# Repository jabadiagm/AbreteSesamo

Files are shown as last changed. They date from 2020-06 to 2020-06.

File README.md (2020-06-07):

# Ábrete Sésamo
Detector de proximidad / apertura de puertas por bluetooth

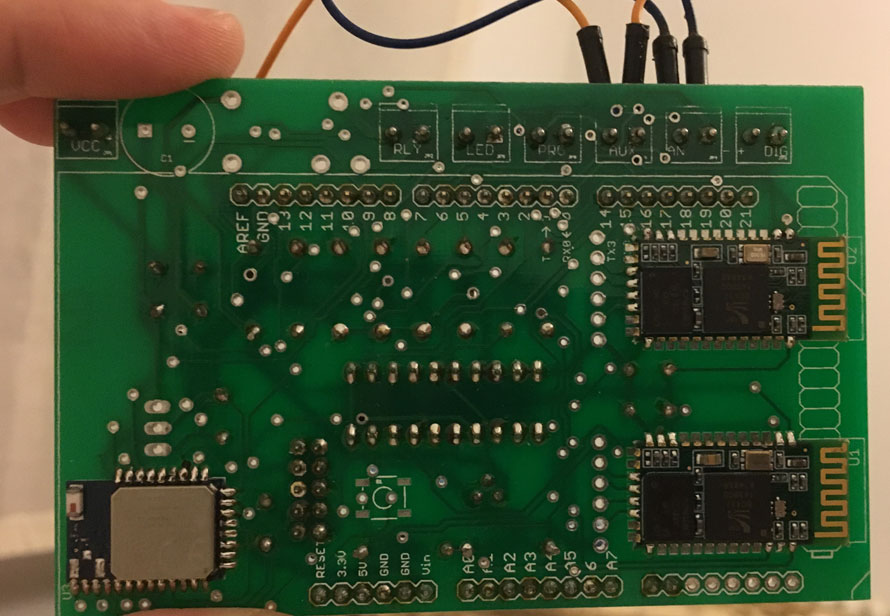
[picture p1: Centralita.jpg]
Centralita


Ábrete Sésamo es un detector de proximidad basado en bluetooth que permite abrir la puerta de un hogar o de un garaje al detectar un dispositivo bluetooth dentro de un rango de 10m, aproximadamente. La centralita está formada por un arduino mega y una placa auxiliar. La placa contiene un relé para conectar al circuito de apertura y tres chips de bluetooth (2xHC05 + BLE112). El primer HC05 sirve para detectar teléfonos anteriores a los smartphones. El segundo HC05 detecta smartphones con bluetooth 1-3. Y el BLE112 sirve para smartphones con bluetooth 4. Los smartphones deben incluir una aplicación que se comunique con la centralita.

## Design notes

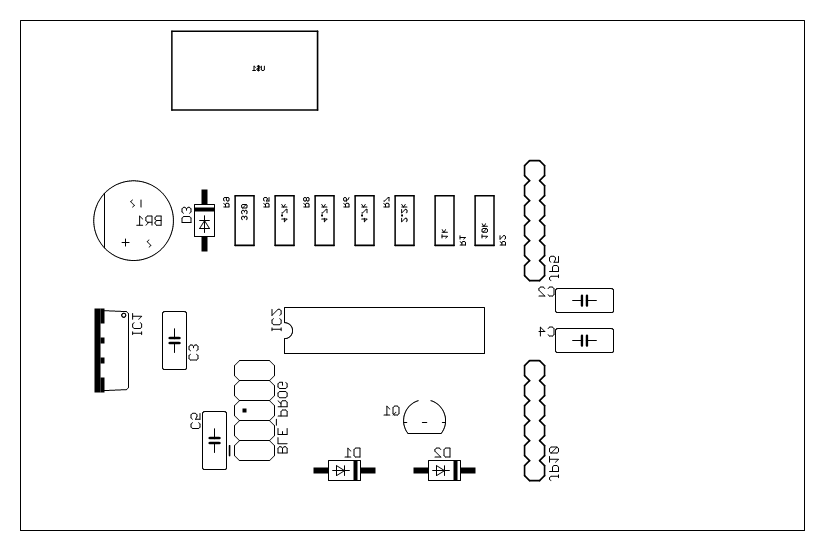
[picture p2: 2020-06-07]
eagle/Images for gerber/prototipo_2_0.GBO.png

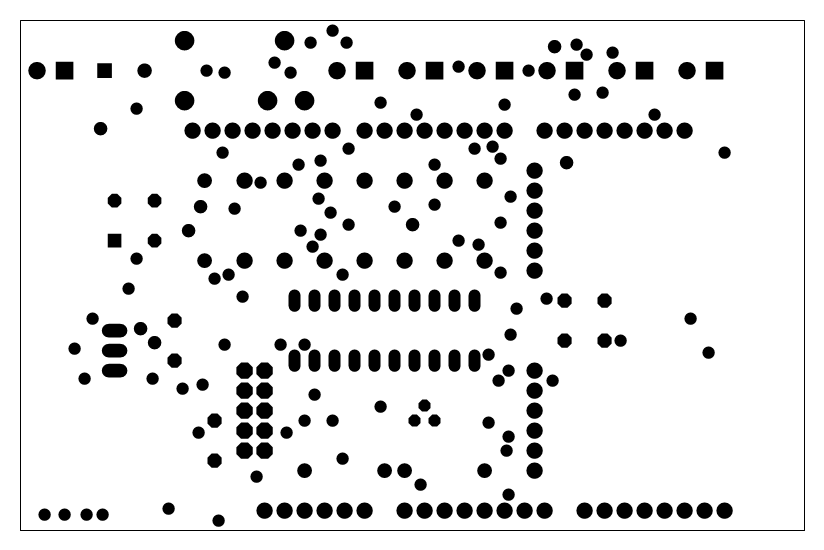
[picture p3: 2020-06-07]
eagle/Images for gerber/prototipo_2_0.GBS.png

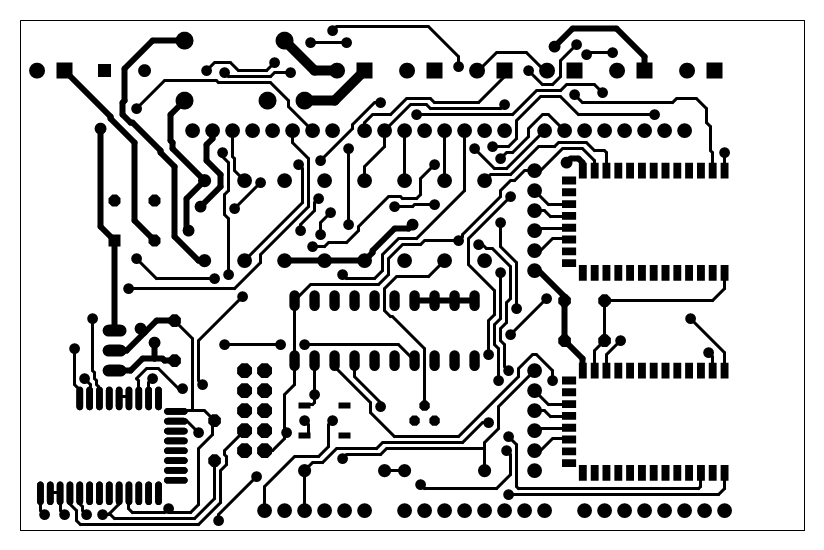
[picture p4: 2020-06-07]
eagle/Images for gerber/prototipo_2_0.GTL.png

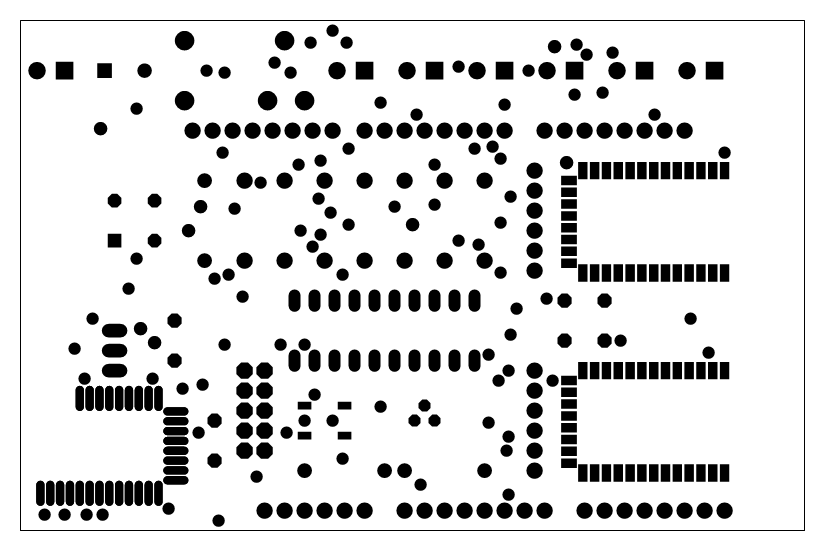
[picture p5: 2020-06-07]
eagle/Images for gerber/prototipo_2_0.GTS.png

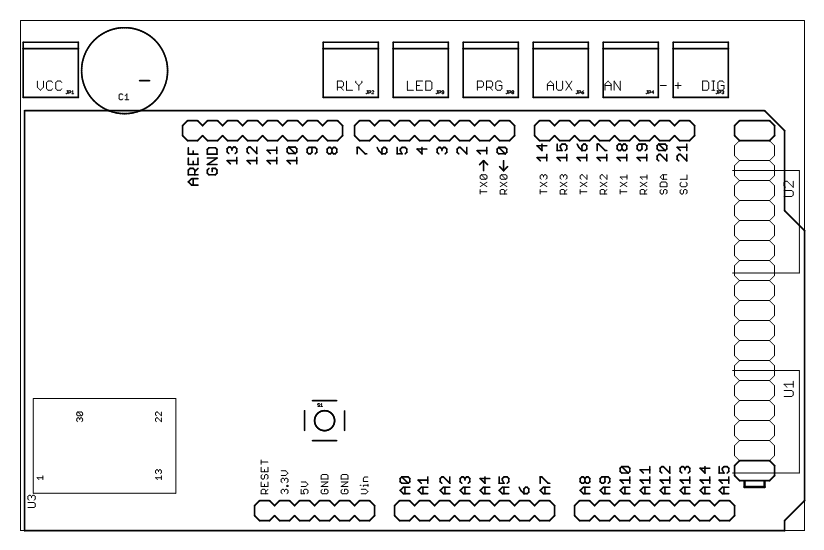
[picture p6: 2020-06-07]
eagle/Images for gerber/prototipo_2_0.GTO.png

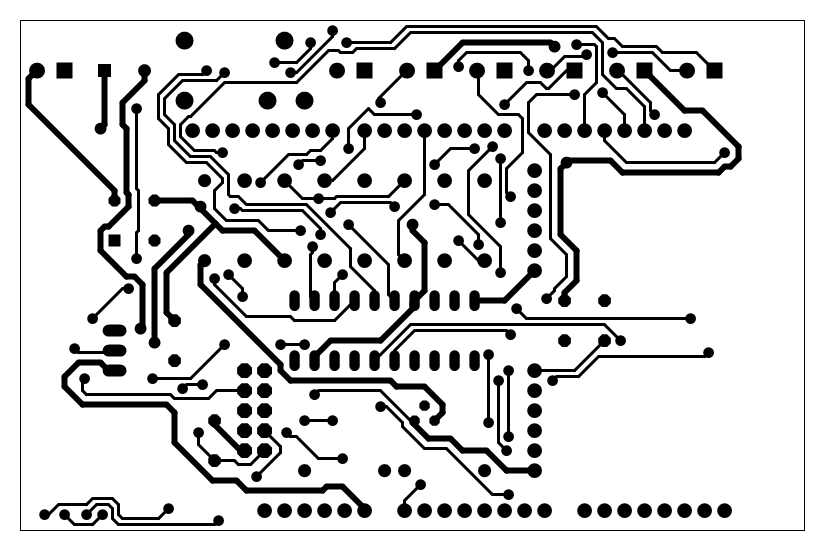
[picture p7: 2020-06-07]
eagle/Images for gerber/prototipo_2_0.GBL.png

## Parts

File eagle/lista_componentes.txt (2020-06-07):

Partlist

Exported from prototipo_2_0.sch at 14/11/2012 22:06:32

EAGLE Version 6.1.0 Copyright (c) 1988-2012 CadSoft

Assembly variant: 

Part     Value           Device                Package                Library                    Sheet

BLE_PROG M05X2PTH        M05X2PTH              AVR_ICSP               SparkFun-Connectors        1
BR1      W05G            W05G                  WOG                    dbridge                    1
C1       500uF           CAP_POLPTH4           CPOL-RADIAL-1000UF-25V SparkFun-Passives          1
C2       100n            C5/3                  C5B3                   capacitor-wima             1
C3       100n            C5/3                  C5B3                   capacitor-wima             1
C4       100n            C5/3                  C5B3                   capacitor-wima             1
C5       100n            C5/3                  C5B3                   capacitor-wima             1
D1       1N4004          1N4004                DO41-10                diode                      1
D2       1N4004          1N4004                DO41-10                diode                      1
D3       1N4004          1N4004                DO41-10                diode                      1
IC1      788TV           788TV                 TO220V                 linear                     1
IC2      74LS245N        74LS245N              DIL20                  adafruit                   1
JP1      VCC             M023.5MM              SCREWTERMINAL-3.5MM-2  SparkFun-Connectors        1
JP2      RLY             M023.5MM              SCREWTERMINAL-3.5MM-2  SparkFun-Connectors        1
JP3      PR1             M023.5MM              SCREWTERMINAL-3.5MM-2  SparkFun-Connectors        1
JP4      PR2             M023.5MM              SCREWTERMINAL-3.5MM-2  SparkFun-Connectors        1
JP5      SPI             M06SIP                1X06                   SparkFun-Connectors        1
JP6      AUX             M023.5MM              SCREWTERMINAL-3.5MM-2  SparkFun-Connectors        1
JP8      PRG             M023.5MM              SCREWTERMINAL-3.5MM-2  SparkFun-Connectors        1
JP9      LED             M023.5MM              SCREWTERMINAL-3.5MM-2  SparkFun-Connectors        1
JP10     SPI             M06SIP                1X06                   SparkFun-Connectors        1
Q1       BC547           BC547                 TO92                   transistor-npn             1
R1       1k              RESISTORPTH-1/4W      AXIAL-0.4              SparkFun-Passives          1
R2       10k             RESISTORPTH-1/4W      AXIAL-0.4              SparkFun-Passives          1
R5       4.7k            RESISTORPTH-1/4W      AXIAL-0.4              SparkFun-Passives          1
R6       4.7k            RESISTORPTH-1/4W      AXIAL-0.4              SparkFun-Passives          1
R7       2.2k            RESISTORPTH-1/4W      AXIAL-0.4              SparkFun-Passives          1
R8       4.7k            RESISTORPTH-1/4W      AXIAL-0.4              SparkFun-Passives          1
R9       330             RESISTORPTH-1/4W      AXIAL-0.4              SparkFun-Passives          1
S1       RESET           SWITCH-MOMENTARY-2SMD TACTILE_SWITCH_SMD     SparkFun-Electromechanical 1
U$1      RELAYPTH4       RELAYPTH4             RELAY-JZC              SparkFun-Electromechanical 1
U$2      ARDUINOMEGA_100 ARDUINOMEGA_100       ARDUINOMEGA_100        prymia                     1
U1       HC_05           HC_05                 BLUETOOTH_SMD          SerialPortBluetooth        1
U2       HC_05           HC_05                 BLUETOOTH_SMD          SerialPortBluetooth        1
U3       BLE112          BLE112-A-VISUAL       BLE112-A               sf-bluegiga                1

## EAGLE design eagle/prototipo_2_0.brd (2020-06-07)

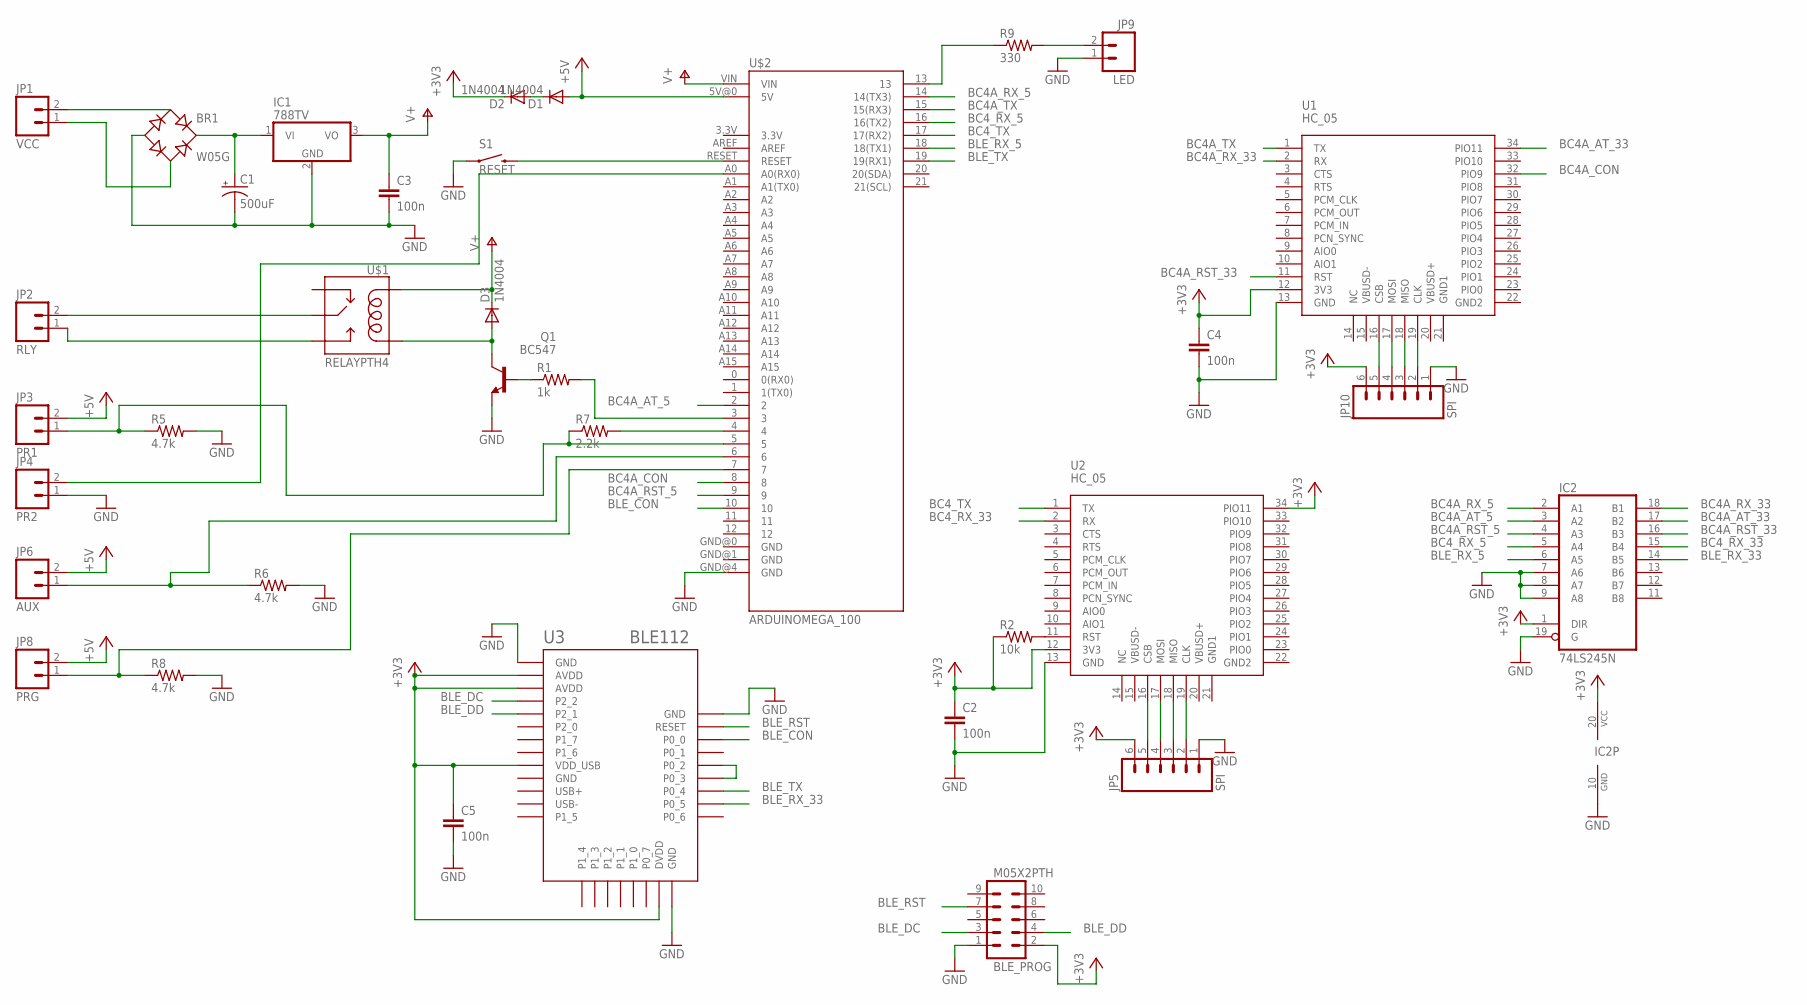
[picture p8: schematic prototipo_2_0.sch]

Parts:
BLE_PROG: M05X2PTH; AVR_ICSP
BR1: W05G; WOG
C1: 500uF; CPOL-RADIAL-1000UF-25V
C2, C3, C4, C5: 100n; C5B3
D1, D2, D3: 1N4004; DO41-10
IC1: 788TV; TO220V
IC2: 74LS245N; DIL20
JP1: VCC; SCREWTERMINAL-3.5MM-2
JP2: RLY; SCREWTERMINAL-3.5MM-2
JP3: PR1; SCREWTERMINAL-3.5MM-2
JP4: PR2; SCREWTERMINAL-3.5MM-2
JP5, JP10: SPI; 1X06
JP6: AUX; SCREWTERMINAL-3.5MM-2
JP8: PRG; SCREWTERMINAL-3.5MM-2
JP9: LED; SCREWTERMINAL-3.5MM-2
Q1: BC547; TO92
R1: 1k; AXIAL-0.4
R2: 10k; AXIAL-0.4
R5, R6, R8: 4.7k; AXIAL-0.4
R7: 2.2k; AXIAL-0.4
R9: 330; AXIAL-0.4
S1: RESET; TACTILE_SWITCH_SMD
U1, U2: HC_05; BLUETOOTH_SMD
U3: BLE112; BLE112-A
U$1: RELAYPTH4; RELAY-JZC
U$2: ARDUINOMEGA_100

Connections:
+3V3: BLE_PROG.2, C2.1, C4.1, C5.1, D2.C, IC2.1 (DIR), IC2.20 (VCC), JP5.6, JP10.6, R2.P$1 (1), U1.12 (3V3), U2.12 (3V3), U2.34 (PIO11), U3.AVDD1 (AVDD), U3.AVDD2 (AVDD), U3.DVDD, U3.VDD_USB
+5V: D1.A, JP3.2, JP6.2, JP8.2, U$2.5V@0 (5V)
BC4A_AT_5: IC2.3 (A2), U$2.2
BC4A_AT_33: IC2.17 (B2), U1.34 (PIO11)
BC4A_CON: U1.32 (PIO9), U$2.8
BC4A_RST_5: IC2.4 (A3), U$2.9
BC4A_RST_33: IC2.16 (B3), U1.11 (RST)
BC4A_RX_5: IC2.2 (A1), U$2.14 (14(TX3))
BC4A_RX_33: IC2.18 (B1), U1.2 (RX)
BC4A_TX: U1.1 (TX), U$2.15 (15(RX3))
BC4_RX_5: IC2.5 (A4), U$2.16 (16(TX2))
BC4_RX_33: IC2.15 (B4), U2.2 (RX)
BC4_TX: U2.1 (TX), U$2.17 (17(RX2))
BLE_CON: U3.P0_0, U$2.10
BLE_DC: BLE_PROG.3, U3.P2_2
BLE_DD: BLE_PROG.4, U3.P2_1
BLE_RST: BLE_PROG.7, U3.RESET
BLE_RX_5: IC2.6 (A5), U$2.18 (18(TX1))
BLE_RX_33: IC2.14 (B5), U3.P0_5
BLE_TX: U3.P0_4, U$2.19 (19(RX1))
GND: BLE_PROG.1, BR1.-, C1.2 (-), C2.2, C3.2, C4.2, C5.2, IC1.2 (GND), IC2.7 (A6), IC2.8 (A7), IC2.9 (A8), IC2.10 (GND), IC2.19 (G), JP4.1, JP5.1, JP9.1, JP10.1, Q1.1 (E), R5.P$2 (2), R6.P$2 (2), R8.P$2 (2), S1.1, U1.13 (GND), U2.13 (GND), U3.GND1 (GND), U3.GND2 (GND), U3.GND3 (GND), U3.GND4 (GND), U$2.GND@4 (GND)
unnamed: R2.P$2 (2), U2.11 (RST)
unnamed: D1.C, D2.A
unnamed: BR1.+, C1.1 (+), IC1.1 (VI)
unnamed: R1.P$2 (2), U$2.3
unnamed: Q1.2 (B), R1.P$1 (1)
unnamed: D3.A, Q1.3 (C), U$1.1 (COIL2)
unnamed: JP2.1, U$1.3 (NO)
unnamed: JP2.2, U$1.4 (MAIN)
unnamed: S1.3 (2), U$2.RESET
unnamed: U3.P0_2, U3.P0_3
unnamed: JP5.2, U2.19 (CLK)
unnamed: JP5.3, U2.18 (MISO)
unnamed: JP5.4, U2.17 (MOSI)
unnamed: JP5.5, U2.16 (CSB)
unnamed: JP10.5, U1.16 (CSB)
unnamed: JP3.1, R5.P$1 (1), R7.P$1 (1), U$2.5
unnamed: JP6.1, R6.P$1 (1), U$2.6
unnamed: R7.P$2 (2), U$2.4
unnamed: JP8.1, R8.P$1 (1), U$2.7
unnamed: JP10.4, U1.17 (MOSI)
unnamed: R9.P$1 (1), U$2.13
unnamed: JP9.2, R9.P$2 (2)
unnamed: JP10.3, U1.18 (MISO)
unnamed: JP10.2, U1.19 (CLK)
unnamed: JP4.2, U$2.A0 (A0(RX0))
V+: C3.1, D3.C, IC1.3 (VO), U$1.5 (COIL1), U$2.VIN
VCC1: BR1.AC1, JP1.2
VCC2: BR1.AC2, JP1.1

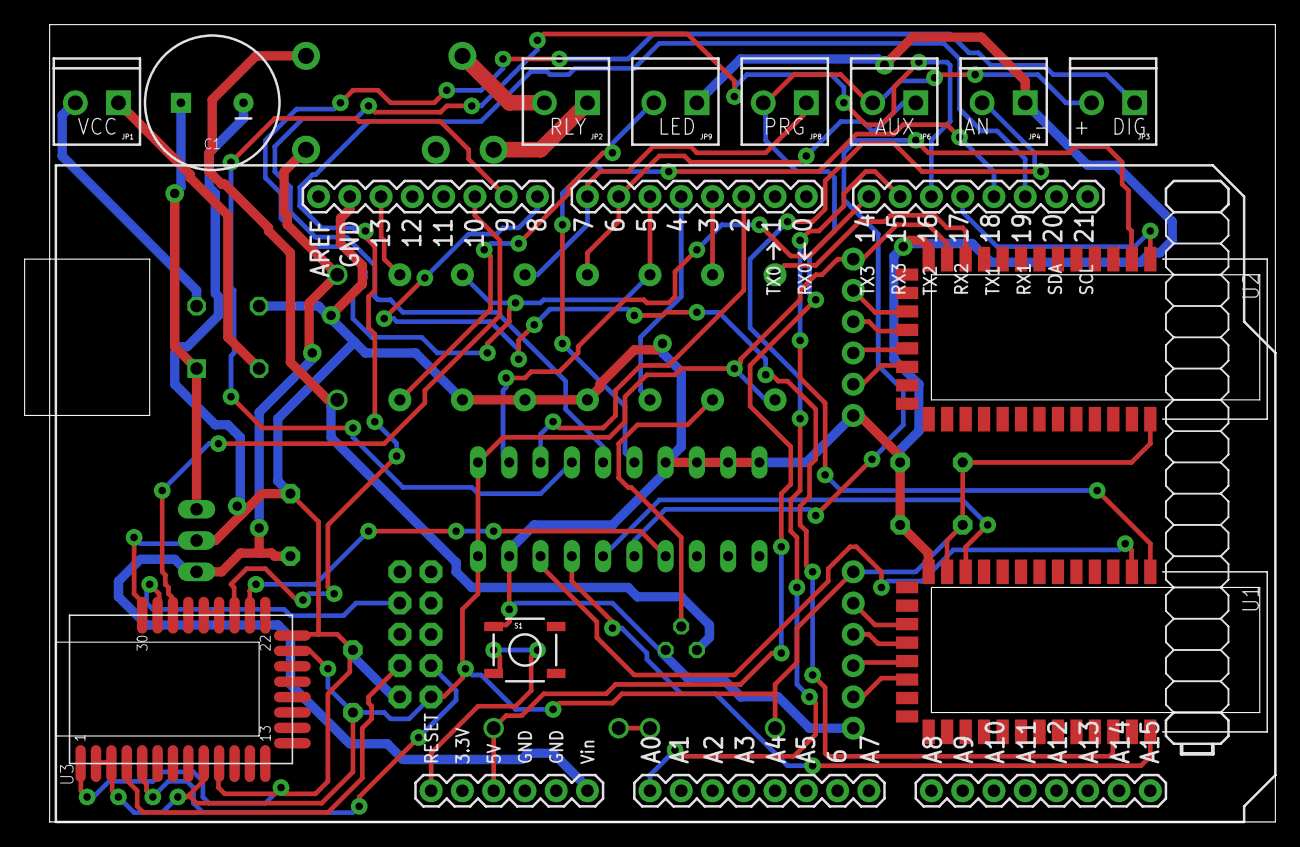
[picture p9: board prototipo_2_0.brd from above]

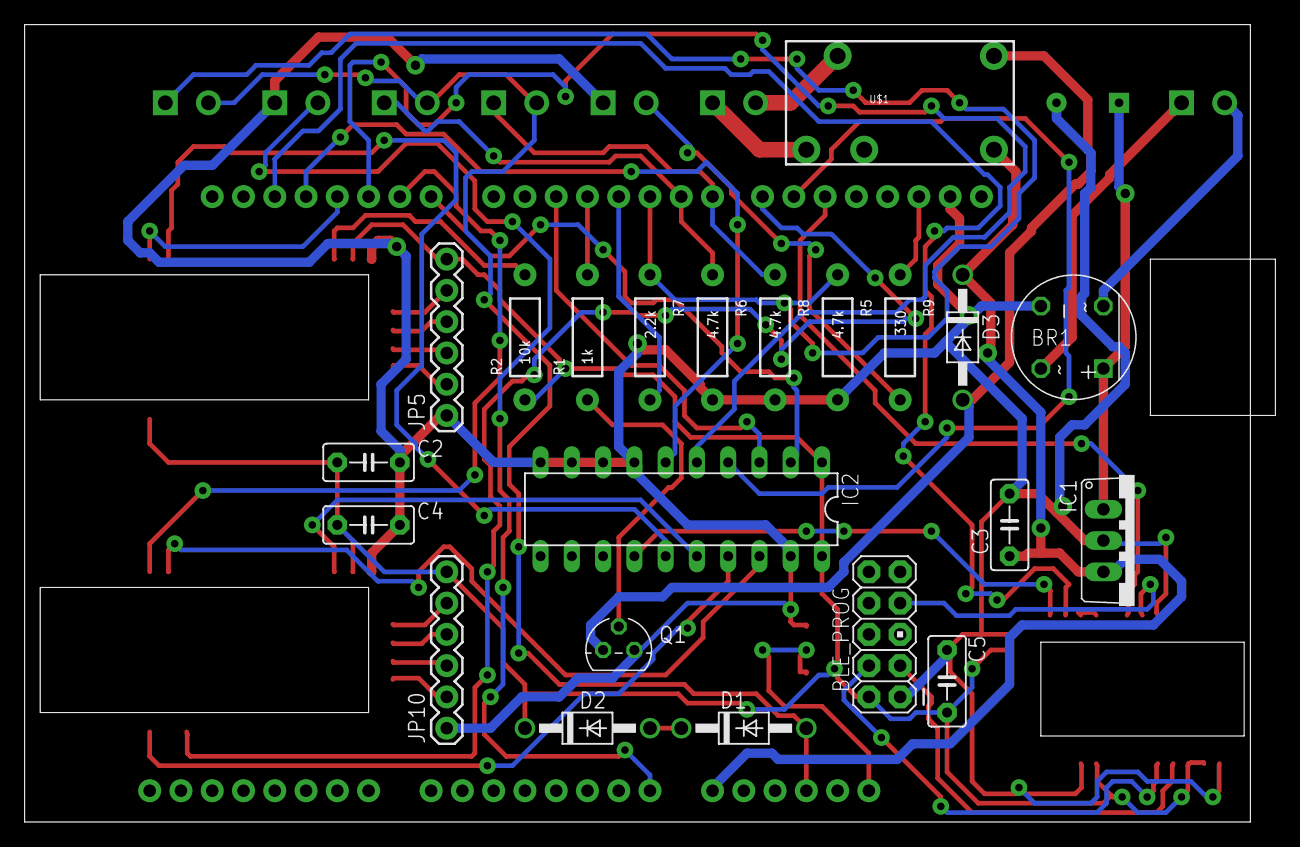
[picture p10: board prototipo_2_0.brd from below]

Board: 2 copper layers, 101.6 x 64.8 mm, 35 parts (22 on the bottom side), 49 nets.

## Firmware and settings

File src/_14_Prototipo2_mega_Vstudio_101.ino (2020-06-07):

#include "EEPROM.h"
 
#define devices_size 20 //number of bt devices discovered nearby
//#define agenda_size 10
#define bc4_serial Serial2 //Serial2
#define bc4a_serial Serial3 //Serial3
#define bt4_serial Serial1
#define bc4
#define bc4a
#define bt4
#define mega
#ifdef mega
  #define n_passwords 128
#endif
boolean echo=true; //true to send debug data through serial port
const int led = 13; //
const int iwrap=3; //bluegiga software version
const boolean presence_inverter=false; //true to invert presence signal
const int bc4a_AT_mode=2; //bc4a AT pin. true to enter command mode, false to accept connections
const int door_relay=3; //true to close switch
const int usound2proximity=4; //brigde between ultrasound & presense pin
const int proximity_sensor=5; //true to indicate presense, unless presence_inverter=true
const int door_sensor=6;
const int program_button=7;
const int bc4a_connection=8; //bc4a connection indicator pin
const int bc4a_reset=9; //bc4a reset pin
const int bt4_connection=10; //bt4 connection indicator pin
const int ultrasound_sensor = A0; 
//timing
#define time_cycle_length 10000 //max time to reset bluetooth presence list
#define time_relay_closed 2000 //time to keep relay active to open door
#define time_delay_after_door_closed 5000 //time given to people going out to disappear
#define time_out 60000 //time given to bluetooth module to answer
#define time_bc4_Connection 60000 //time given to a bluetooth connection to send mac before closing
int bc4_step;
int bc4a_step;
int bt4_step;
//unsigned long wt32_pair_time=15000; //time waiting for PAIR events

String bc4_last_rname; //last probed address
//String discovered[devices_size]; //devices discovered
unsigned char bt_discovered[devices_size][6];
int n_discovered=0; //number of devices found
//String agenda[agenda_size]; //authorized devices
//int n_agenda=0; //number of devices contained in agenda
int eeprom_nusers; //number of clients stored in eeprom
boolean program_mode=false; //true to enter name discovery
boolean ready2open=false; //true to turn on LED
boolean wasready2open=false; //true if the las cycle there was a valid user

extern int __bss_end;
extern void *__brkval;

int get_free_memory()
{
  int free_memory;

  if((int)__brkval == 0)
    free_memory = ((int)&free_memory) - ((int)&__bss_end);
  else
    free_memory = ((int)&free_memory) - ((int)__brkval);

  return free_memory;
}


   
  //boolean mac_found();
  //void door_open();
  //void door_closed();
  //void add_discovered();
  //void add_agenda();
  String bc4_get_address(String line);
  //String wt32_get_paired_address(String line);
  
  void decrypt5(char *line) {
    //decrypts a 5 bytes message
  }
  boolean check_signature5(char *line) {
    //signature verif. for a 5 bytes message
    return true;
  }
  void bc4_init() {
    bc4_serial.begin(38400);
    bc4_serial.print(F("AT+RESET\r\n"));  //restart BC4
    delay(1000);
    bc4serial_discard_line(1000);
    bc4_serial.print(F("AT+ROLE=1\r\n")); //Master mode
    delay(1000);
    bc4serial_discard_line(2000);
    bc4_serial.print(F("AT+INIT\r\n")); //init SPP profile
    bc4serial_discard_line(1000);
    delay(500);
    bc4_serial.print(F("AT+IAC=9E8B33\r\n")); //all devices discoverable
    bc4serial_discard_line(1000);
    delay(500);
    bc4_serial.print(F("AT+PSWD=0000\r\n")); //PASS CODE="0000"
    bc4serial_discard_line(1000);
    delay(1000);    
    bc4_serial.print(F("AT+NAME=bc4_Abrete_Sesamo\r\n")); //device name
    delay(1000);  
    bc4serial_discard_line(1000);
    bc4_serial.print(F("AT+CLASS=0\r\n")); //no CoD
    delay(1000);
    bc4serial_discard_line(1000);
    bc4_serial.print(F("AT+INQM=1,99,10\r\n")); //RSSI inquiry, max 999 devices/48*1.28"
    delay(1000);
    bc4serial_discard_line(1000);
    bc4_step=0; //begins cycle
  }
  void bc4_loop() {
    static int counter=0; 
    if (bc4_step==0) {
      bc4_serial.print("AT+INQ\r\n"); //start discovery
      bc4_step=1;
    }
    if (bc4_step==1) {
      return; //waits for devices or "OK" to finish 
    }    
    if (bc4_step==2) {
       if (counter<n_discovered) { //devices to identify
         char at_command[26];
         bc4_last_rname=get_discovered_Hex_bd_address(counter);
         at_command[0]='A';
         at_command[1]='T';
         at_command[2]='+';
         at_command[3]='R';
         at_command[4]='N';
         at_command[5]='A';
         at_command[6]='M';
         at_command[7]='E';
         at_command[8]='?';
         at_command[9]=bc4_last_rname.charAt(0);
         at_command[10]=bc4_last_rname.charAt(1);
         at_command[11]=bc4_last_rname.charAt(2);
         at_command[12]=bc4_last_rname.charAt(3);
         at_command[13]=',';
         at_command[14]=bc4_last_rname.charAt(4);
         at_command[15]=bc4_last_rname.charAt(5);
         at_command[16]=',';
         at_command[17]=bc4_last_rname.charAt(6);
         at_command[18]=bc4_last_rname.charAt(7);
         at_command[19]=bc4_last_rname.charAt(8);
         at_command[20]=bc4_last_rname.charAt(9);
         at_command[21]=bc4_last_rname.charAt(10);
         at_command[22]=bc4_last_rname.charAt(11);
         at_command[23]='\r';
         at_command[24]='\n';
         at_command[25]=0;
         //bc4_serial.print("at+rname?9C18,74,C39E1b\r\n"); //gets name
         bc4_serial.print(at_command);
         counter++;
         bc4_step=3;
         return;
       } else {
         bc4_step=0;
         counter=0;
         //check if program button is still pressed
         if (program_mode & digitalRead(program_button)==LOW) program_mode=false;
         return;
       }
    }     
  }

  void bc4_event(String line) { //process input
    if (bc4_step==1) {
      if (line.indexOf("OK")!=-1) { //end of inquiry. restart
        bc4_step=0;
        //Serial.print("AT");
        //print_discovered();
        if (program_mode) { //enters name discovery mode
          echo_println("In program mode");
          bc4_step=2;
        }
        return;
      } else { //then, must be a device address
        add_discovered(bc4_get_address(line));
        return;
      }  
    }
    if (bc4_step==3) {
      if (line.indexOf("FAIL")!=-1) { //name not found
        bc4_step=2;
      } else {
        echo_print("RNAME: ");
        echo_print(line);
        bc4_process_RNAME(line); //looks for new user
        bc4_step=4; //name found, waits for "OK"
      }
      return; //
    }    
    if (bc4_step==4) {
      bc4_step=2;
      return; //
    }    
    
  }

void bc4serial_discard_line(unsigned int bc4time_out) { //wait for a whole line to te received
  long time_start; //
  time_start=millis();
  //String line;
  while ((millis()-time_start) < bc4time_out) {
    if (bc4_serial.available()) {
      int inByte = bc4_serial.read();
      //line.concat(char(inByte));      
      if (inByte=='\n') {
        //Serial.print("-D-"+line);
        return; //end of line
      }
    }
  }
  Serial.println(F("-D-Time_Out"));
} 

  void bc4a_init() {
    bc4a_serial.begin(38400);
    echo_println("bc4a start init");
    digitalWrite (bc4a_AT_mode,true); //AT=true to accept commands
    digitalWrite (bc4a_reset,false); //AT must be true on chip start
    delay(1000);
    digitalWrite (bc4a_reset,true); //AT must be true on chip start
    delay(1500);
    bc4a_serial.print(F("AT+ROLE=0\r\n")); //Slave mode
    echo_println("AT+ROLE=0");
    bc4aserial_discard_line(1500);
    bc4a_serial.print(F("AT+INIT\r\n")); //init SPP profile
    echo_println("AT+INIT");
    bc4aserial_discard_line(2000);
    bc4a_serial.print(F("AT+PSWD=0000\r\n")); //PASS CODE="0000"
    echo_println("AT+PSWD=0000");
    bc4aserial_discard_line(1500);
    bc4a_serial.print(F("AT+NAME=Trookey-Prymia\r\n")); //device name
    echo_println("AT+NAME=bc4a_Abrete_Sesamo");
    bc4aserial_discard_line(1500);
    bc4a_serial.print(F("AT+CLASS=5a020c\r\n")); //telephone CoD
    echo_println("AT+CLASS=0");
    bc4aserial_discard_line(1500);
    digitalWrite (bc4a_AT_mode,false); //AT=false to accept connections
    echo_println("bc4a init");
    bc4a_step=0; //begins cycle
  }

  void bc4a_loop() {
    static long time_connection_start;
    if (bc4a_step==0) {
      if (digitalRead(bc4a_connection)==HIGH) { //incoming connection
        time_connection_start=millis(); //stores start time
        bc4a_serial.println("Prymia_2.0>");
        bc4a_step=1; 
        echo_println("bc4a Connection on");
      }
      return;
    }
    if (bc4a_step==1) {
      if (digitalRead(bc4a_connection)==LOW) {
        bc4a_step=0; //connection finished
        echo_println("bc4a Connection off");
      }
      long time_now;
      time_now=millis();
      
      return;
    }
  }

  void bc4a_event(String line) {
    line.toLowerCase();
    if (line.indexOf("mac=")==0) { //phone id
      echo_println("Process MAC");
      bc4a_process_MAC(line);
      return;
    }
    if (line.indexOf("alta=")==0) { //phone id
      echo_println("Process checkin");
      bc4a_process_checkin(line);
      return;
    }    
    if (line.indexOf("baja=")==0) { //phone id
      echo_println("Process checkout");
      bc4a_process_checkout(line);
      return;
    } 
    if (line.length()==14) { //12chars+cr+lf
      String mac;
      mac=line.substring(0,12);
      if (is_valid_hex_String(mac)) { //it may be a valid mac
        bc4a_serial.println("OK");
        echo_println(mac);
        add_discovered(mac);
        return;
      }
    }
    bc4a_serial.println("FAIL");
  }
  void bc4a_process_MAC(String line) {
    //phone identification
    //MAC=aabbccddeeff+cr+lf
    String mac;
    if (line.length()!=18) {
      echo_println("Wrong length");
      bc4a_serial.println("ERROR");
      return;
    } 
    mac=line.substring(4,16);
    echo_print("MAC:");
    //echo_println(line);
    if (is_valid_hex_String(mac)) { //it may be a valid mac
      bc4a_serial.println("OK");
      echo_println(mac);
      add_discovered(mac);
      return;
    } else {
      echo_println("Invalid");
      bc4a_serial.println("ERROR");
    }
  }

void bc4a_process_checkin(String line) {
  //phone checkin
  //ALTA=xxyyzzxxyyzz,pppppppp+CR+LF
  String Str_mac;
  String Str_password;
  char str_mac[6];
  char str_password[9];
  byte return_code;
  if (line.length()==10) { //###depuracion.
    Str_password=line.substring(5,8);
    if (Str_password=="666") {
      eeprom_init();
      eeprom_init2();
      echo_println("-->EEPROM RESET<--");
      return;    
    }
  }
  if (line.length()!=28) {
    echo_println("Wrong length");
    bc4a_serial.println("ERROR");
    return;
  } 
  Str_mac=line.substring(5,17);
  Str_password=line.substring(18,26);
  echo_print("MAC: ");
  echo_println(Str_mac);
  echo_print("Pass: ");
  echo_println(Str_password);
  Str_password.toCharArray(str_password,9);
  if (!is_valid_hex_String(Str_mac)) { //not hex String
    bc4a_serial.println("ERROR");
    return;
  }
  hex_String_2_string(Str_mac, str_mac) ;
  return_code=process_name (str_mac,str_password, 8);
  if (return_code==0) {
    bc4a_serial.println("OK");
  } else {
    echo_println("Password Already Used.");
    bc4a_serial.println("ERROR(1)");
  }
}  

  void bc4a_process_checkout(String line) {
    //phone identification
    //BAJA=pppppppp99+cr+lf
    String Str_password;
    char str_password[11];
    char empty[6]; //process_name request a bd_address, but unused to checkout
    if (line.length()!=17) {
      echo_println("Wrong length");
      bc4a_serial.println("ERROR");
      return;
    } 
    Str_password=line.substring(5,15);
    echo_print("PASS:");
    echo_println(Str_password);
    Str_password.toCharArray(str_password,11);
    if (process_name (empty,str_password, 10)==0) { //check if checkout pass is correct
      bc4a_serial.println("OK");
      return;
    } else {
      echo_println("Unused or Invalid Password");
      bc4a_serial.println("ERROR");
    }
  }
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
   void loop(){ 
      #ifdef bc4 
        String bc4_line;
      #endif
      #ifdef bc4a
        String bc4a_line;
      #endif
      #ifdef bt4
        String bt4_line;
      #endif      
     unsigned long time_start_cycle;
     unsigned long time_bc4_last_command; //last request
     unsigned long time_bc4a_last_command;
     unsigned long time_bt4_last_command;
     time_start_cycle=millis();
     time_bc4_last_command=millis();
     time_bc4a_last_command=millis();
     while (true) {
        #ifdef bc4 
          bc4_loop();
        #endif
        #ifdef bc4a
          bc4a_loop();
        #endif
        #ifdef bt4
          bt4_loop();
        #endif
        #ifdef bc4 
          while (bc4_serial.available()) {
            int inByte = bc4_serial.read();
            bc4_line.concat(char(inByte));
            if (inByte=='\n') {
              //Serial.print("---->"+bc4_line);
              time_bc4_last_command=millis();
              bc4_event(bc4_line);
              bc4_line="";
            }
          } 
          //bc4 time out
          if ((millis()-time_bc4_last_command) >time_out) { //lost sync with bc4
            bc4_init(); //reset & init bc4
            time_bc4_last_command=millis();
            program_mode=0;
          }
        #endif
        #ifdef bc4a 
          while (bc4a_serial.available()) {
            int inByte = bc4a_serial.read();
            bc4a_line.concat(char(inByte));
            if ((inByte=='\n')) {
              Serial.print("bc4a->"+bc4a_line);
              time_bc4a_last_command=millis();
              bc4a_event(bc4a_line);
              bc4a_line="";
            }
          } 
          //bc4a time out
          //if ((millis()-time_bc4a_last_command) >time_out) { //lost sync with bc4
          //  bc4a_init(); //reset & init bc4a
          //  time_bc4a_last_command=millis();
          //  program_mode=0;
          //}
        #endif
        #ifdef bt4
          while (bt4_serial.available()) {
            int inByte = bt4_serial.read();
            bt4_line.concat(char(inByte));
            if ((inByte=='\n')) {
              Serial.print("bt4->"+bt4_line);
              time_bt4_last_command=millis();
              bt4_event(bt4_line); //shared API with bc4a
              bt4_line="";
            }
          } 
          //bc4a time out
          //if ((millis()-time_bc4a_last_command) >time_out) { //lost sync with bc4
          //  bc4a_init(); //reset & init bc4a
          //  time_bc4a_last_command=millis();
          //  program_mode=0;
          //}
        #endif
        /*
        if (digitalRead(program_button)==HIGH) {
          digitalWrite(door_relay,HIGH);
        } else digitalWrite(door_relay,LOW); */
        door_control(); //check physical presence+bt presence+door state
        //check program button
        if (digitalRead(program_button)==HIGH & !program_mode) {
          program_mode=true;
          int contador;
          unsigned long origen;
          boolean retorno;
          origen=millis();
          for (contador=0;contador<10;contador++) {
            retorno=is_any_user_present();
          }
        }
        //ultrasound check
        if (analogRead(ultrasound_sensor)<30) {
          digitalWrite(usound2proximity,HIGH);
          //Serial.print("-D-HIGH");
          //delay(50);
        } else {
          digitalWrite(usound2proximity,LOW);
          //Serial.print("-D-LOW");
          //delay(50);
        }
        if ((millis()-time_start_cycle)>time_cycle_length) {
          if (!program_mode) {
            echo_println("Start Cycle");
            if (!ready2open) { // short flash if LED is inactive
              digitalWrite (led,HIGH);
              delay(10);
              digitalWrite (led,LOW);
            }
            reset_discovered(); //reset list of found devices
          }
          time_start_cycle=millis();
        }
     }
   } 
  
  void door_control() {
    //activates/close relay based in 
    //*door state (open/closed)
    //*presence sensor
    //*bluetooth detection
    static boolean door_is_closed=true;
    static boolean door_was_closed=true;
    static boolean people_is_present=false;
    static boolean people_were_present=false;
    static boolean relay_active=false; //estate of main relay
    static unsigned long time_door_relay_activated;
    static unsigned long time_door_closed;
    //static unsigned long time_last_time_door_open; //the 
    //previous values
    door_was_closed=door_is_closed;
    people_were_present=people_is_present;
    //actual values
    door_is_closed=digitalRead(door_sensor);
    people_is_present=digitalRead(proximity_sensor);
    if (presence_inverter) people_is_present=!people_is_present; //for inverted sensors
    if (people_is_present & !people_were_present) echo_println("People on sight");
    if (!door_is_closed & door_was_closed) echo_println("Door open");
    if (door_is_closed & !door_was_closed) {
      time_door_closed=millis();
      echo_println("Door closed");
    }
    if (relay_active) { //door is being open right now
      if ((millis()-time_door_relay_activated)>time_relay_closed) {
        relay_active=false; //disconnect relay after suitable delay
        digitalWrite(door_relay,LOW);
        echo_println("Stop opening door");
      }
      return;
    }
    //main logic
    if (door_is_closed & people_is_present) {
      if ((ready2open | wasready2open)& (millis()-time_door_closed)>time_delay_after_door_closed) { 
        relay_active=true;
        time_door_relay_activated=millis();
        echo_println("Start opening door");
        digitalWrite(door_relay,HIGH); 
      }
    } 
  }

  void add_discovered(String mac) {
  //look for a discovered device in the list. if not present, appends it
    int counter;
    char bd_address[6];
    if (mac.length()!=12) {
      return;  
    }
    hex_String_2_string(mac, bd_address); //converts to 6 bytes address
    if (agenda_is_bd_address_present(bd_address)) return; //device already in list
    //new device
    if (n_discovered<devices_size) { //list not full
      for (counter=0;counter<6;counter++) bt_discovered[n_discovered][counter]=bd_address[counter];
      n_discovered++; 
      echo_print ("Found "+mac+" n=");      
      echo_println (String(n_discovered)); 
      if (!ready2open) { //no valid device found yet
        if (is_any_user_present()) {
          ready2open=true;
          digitalWrite(led,HIGH);
        }
      }
      /*      
      echo_string_serial (bd_address,6);
      Serial.println("Agenda");
      int counter2;
      for (counter=0;counter<n_discovered;counter++) {
        for (counter2=0;counter2<6;counter2++) Serial.print(bt_discovered[counter][counter2],HEX);
        Serial.println(" "); 
      } */
      //Serial.print(bd_address[0],HEX);Serial.print(bd_address[1],HEX);Serial.print(bd_address[2],HEX);Serial.print(bd_address[3],HEX);Serial.print(bd_address[4],HEX);Serial.println(bd_address[5],HEX);
    }  
  }
  void reset_discovered () {
    //reset list of discovered devices to begin a new scan cycle
    if (is_any_user_present()) {
      wasready2open=true; //keeps ready2open for another round
    } else { //
      wasready2open=false;
      ready2open=false;
      digitalWrite(led,LOW);      
    }
    n_discovered=0;
  }
  void get_discovered_bd_address(unsigned int device_number, unsigned char *bd_address) {
    //returns bt address of discovered device in byte format
    int counter;
    for (counter=0;counter<6;counter++) bd_address[counter]=bt_discovered[device_number][counter];
  }
  String get_discovered_Hex_bd_address(unsigned int device_number) {
    //returns bt address of discovered device in Hex String format
    unsigned char bd_address[6];
    get_discovered_bd_address(device_number,bd_address);
    return string_2_Hex_String(bd_address,6);
  }
  boolean is_any_user_present() {
    //compares agenda with eeprom and returns true if any user is present
    int counter;
    int counter2;
    char bd_address[6];
//    Serial.println("nose");
//    while(1);
//    return true; //###depuracion
    for (counter=0;counter<n_discovered;counter++) {
      for (counter2=0;counter2<6;counter2++) bd_address[counter2]=bt_discovered[counter][counter2];
      if (eeprom_is_bd_address_present(bd_address)) return true;
    }
    return false;
  }
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

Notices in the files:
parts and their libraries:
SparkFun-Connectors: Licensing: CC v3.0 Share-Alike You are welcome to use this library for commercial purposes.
